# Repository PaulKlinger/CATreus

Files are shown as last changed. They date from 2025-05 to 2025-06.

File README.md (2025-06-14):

# CATreus

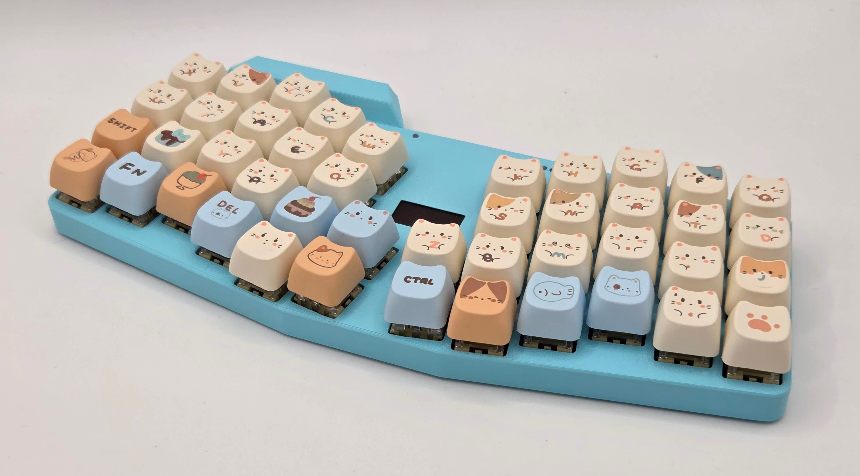
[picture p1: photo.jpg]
photo of keyboard


A wireless keyboard based on the Keyboardio Atreus.

* NRF54L15 Bluetooth SoC (HolyIOT module)
* NPM1300 PMIC for battery management
* 14500 li-ion battery (900mAh)
* 128x64 OLED display (SSD13060based)
* 4 status LEDs, 1 charge LED
* 3D printed [case](/case)
* custom [firmware](/kbd_firmware)
* Kailh Midnight Pro Silent Switches
* MAO profile keycaps ([from Aliexpress](https://www.aliexpress.com/item/1005008664883621.html))
* cat animations by John William Bond (u/Kaimatten), [original video](https://www.reddit.com/r/PixelArt/comments/hoxd95/1_minute_of_1_bit_cat_animations)

Key layout is hardcoded in the firware, I'm using a NEO2 based layout.

## Notes

Programmed via the 5 holes on the top next to the leds, using a custom pogo pin connector.
Spacing is 2.54mm, so can just solder pogo pins to a piece of protoboard.
pinout:
```
   NC    RESET   GND
   3V3   SWDIO   SWCLK
```

Wake button is top left of the center 4 buttons, used to wake the keyboard from sleep mode (30min of inactivity).
UI help by pressing wake + H.

CMD & CTRL keys can be swapped with wake + W for use on Windows/Mac this is persisted per bluetooth connection.

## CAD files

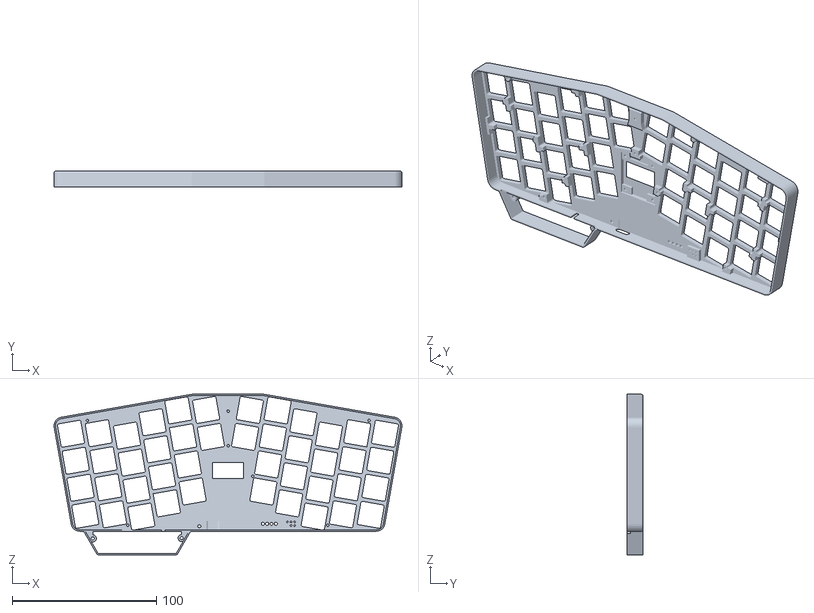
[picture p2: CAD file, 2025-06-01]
case/case_top.stl
240.9 x 10.9 x 111.1

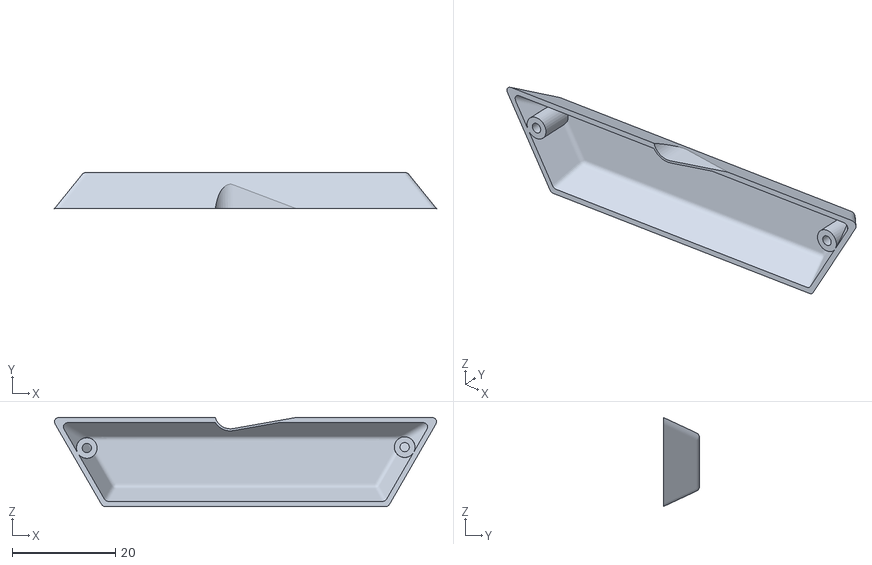
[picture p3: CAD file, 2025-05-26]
case/battery cover.stl
74.0 x 7.00 x 17.3

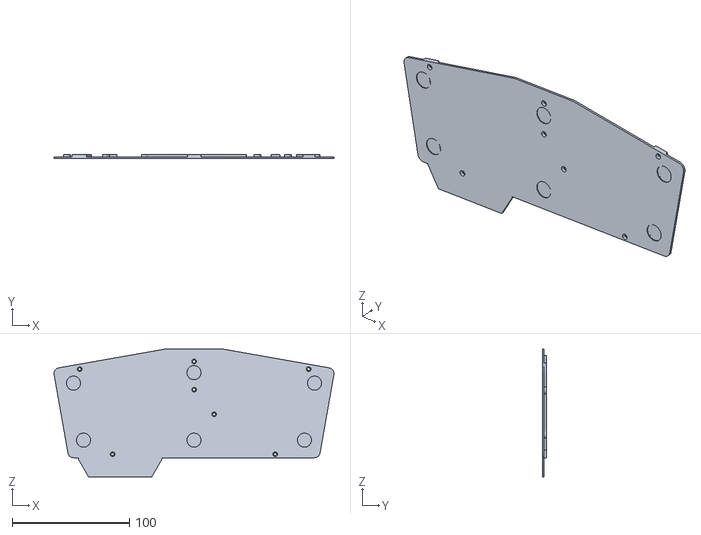
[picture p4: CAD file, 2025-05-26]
case/case_bottom.stl
238.5 x 3.50 x 108.7

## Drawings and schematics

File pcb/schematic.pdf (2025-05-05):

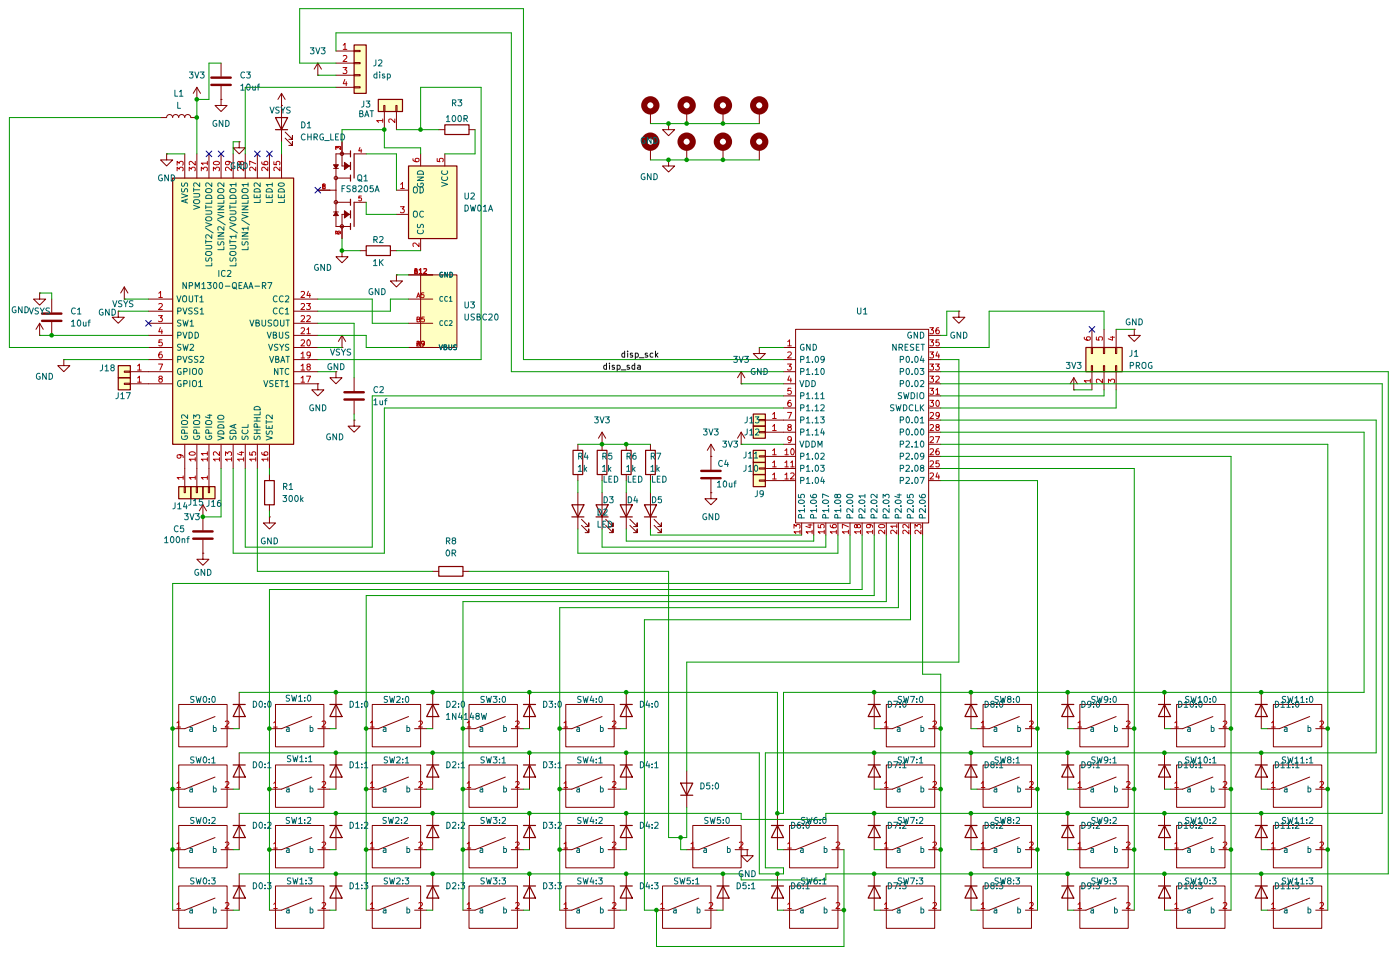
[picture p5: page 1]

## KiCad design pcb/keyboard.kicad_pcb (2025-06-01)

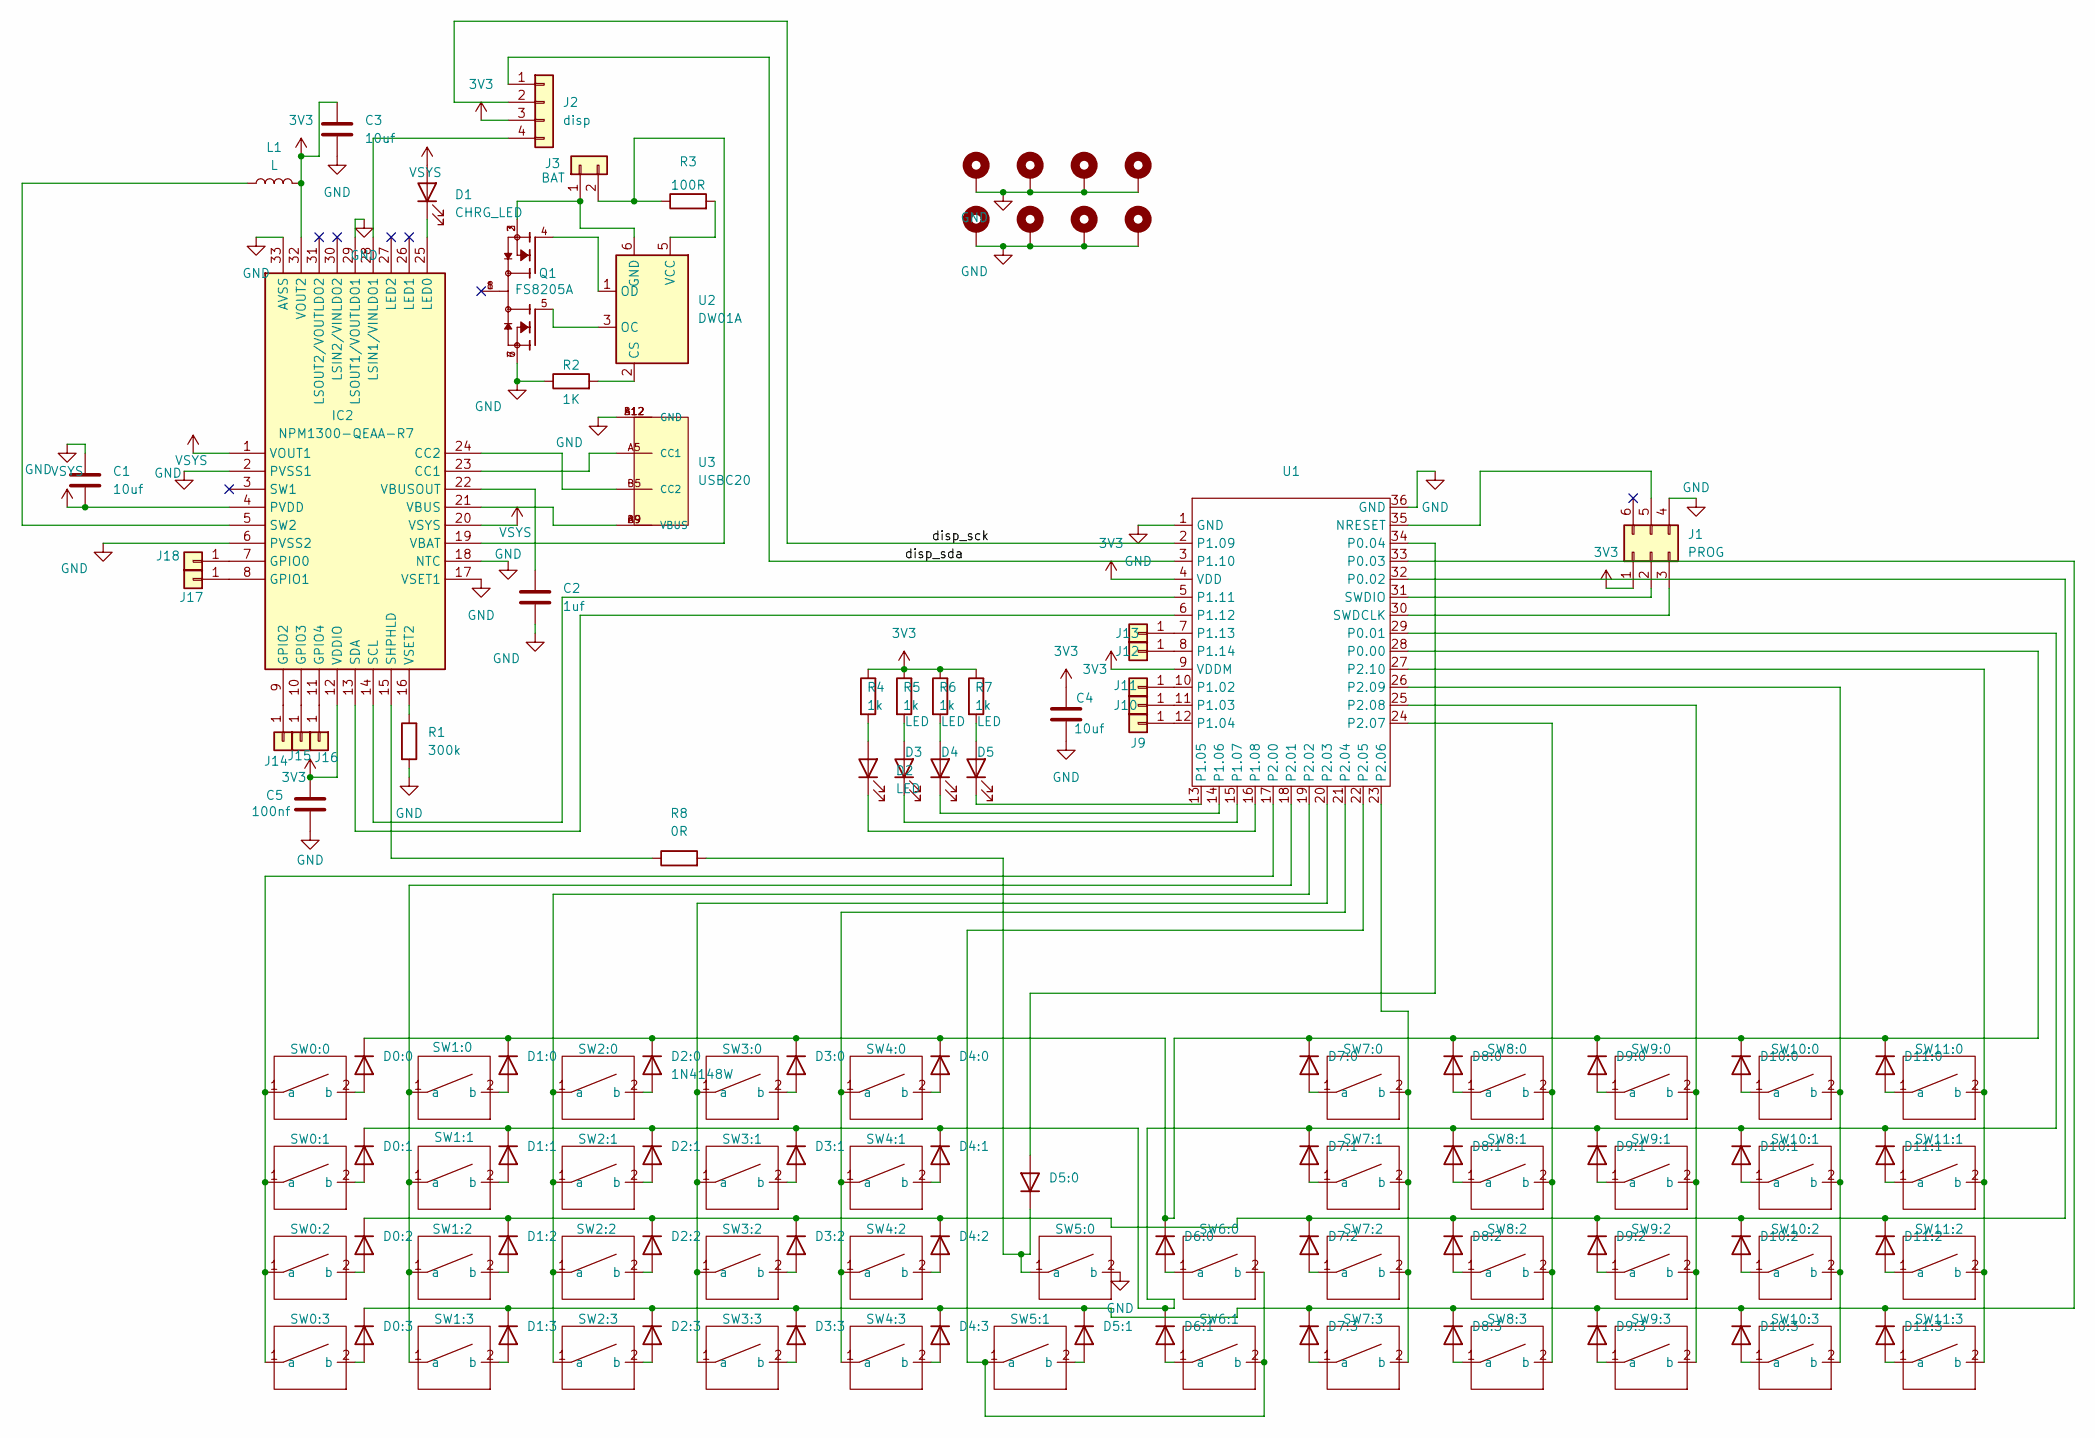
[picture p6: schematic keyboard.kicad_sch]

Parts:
C1, C3, C4: 10uf; C_0805_2012Metric_Pad1.18x1.45mm_HandSolder
C2: 1uf; C_0805_2012Metric_Pad1.18x1.45mm_HandSolder
C5: 100nf; C_0805_2012Metric_Pad1.18x1.45mm_HandSolder
D0:0, D0:1, D0:2, D0:3, D1:0, D1:1, D1:2, D1:3, D2:1, D2:2, D2:3, D3:0, D3:1, D3:2, D3:3, D4:0, D4:1, D4:2, D4:3, D5:0, D5:1, D6:0, D6:1, D7:0, D7:1, D7:2, D7:3, D8:0, D8:1, D8:2, D8:3, D9:0, D9:1, D9:2, D9:3, D10:0, D10:1, D10:2, D10:3, D11:0, D11:1, D11:2, D11:3: Nexperia_CFP3_SOD-123W
D1: CHRG_LED; LED_0805_2012Metric_Pad1.15x1.40mm_HandSolder
D2, D3, D4, D5: LED; LED_0805_2012Metric_Pad1.15x1.40mm_HandSolder
D2:0: 1N4148W; D_SOD-123
H1, H2, H3, H4, H5, H6, H7, H8: MountingHole_Pad; MountingHole_2.2mm_M2_DIN965_Pad
IC2: NPM1300-QEAA-R7; QFN50P500X500X90-33N; Mouser Part Number 949-NPM1300-QEAA-R7
J1: PROG; SWD_PROG_5pin
J2: disp; PinHeader_1x04_P2.54mm_Vertical
J3: BAT; PinHeader_1x02_P2.54mm_Vertical
J9, J10, J11, J12, J13, J14, J15, J16, J17, J18: Conn_01x01; SolderWirePad_1x01_SMD_1x2mm
L1: L; L_1008_2520Metric_Pad1.43x2.20mm_HandSolder
Q1: FS8205A; SOP65P640X120-8N; PARTREV 1.7
R1: 300k; R_0805_2012Metric_Pad1.20x1.40mm_HandSolder
R2: 1K; R_0805_2012Metric_Pad1.20x1.40mm_HandSolder
R3: 100R; R_0805_2012Metric_Pad1.20x1.40mm_HandSolder
R4, R5, R6, R7: 1k; R_0805_2012Metric_Pad1.20x1.40mm_HandSolder
R8: 0R; R_0805_2012Metric_Pad1.20x1.40mm_HandSolder
SW0:0, SW0:1, SW0:2, SW0:3, SW1:0, SW1:1, SW1:2, SW1:3, SW2:0, SW2:1, SW2:2, SW2:3, SW3:0, SW3:1, SW3:2, SW3:3, SW4:0, SW4:1, SW4:2, SW4:3, SW5:0, SW5:1, SW6:0, SW6:1, SW7:0, SW7:1, SW7:2, SW7:3, SW8:0, SW8:1, SW8:2, SW8:3, SW9:0, SW9:1, SW9:2, SW9:3, SW10:0, SW10:1, SW10:2, SW10:3, SW11:0, SW11:1, SW11:2, SW11:3: SW_Cherry_MX_PCB
U1: nrf54l15_holyiot
U2: DW01A; SOT-23-6
U3: USBC20; USBC_6PIN

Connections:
3V3: C3.1, C4.1, C5.1, IC2.12 (VDDIO), IC2.32 (VOUT2), J1.1, J2.3, L1.2, R4.1, R5.1, R6.1, R7.1, U1.4 (VDD), U1.9 (VDDM)
/disp_sck: J2.2, U1.2 (P1.09)
/disp_sda: J2.1, U1.3 (P1.10)
GND: C1.1, C2.2, C3.2, C4.2, C5.2, H1.1, H2.1, H3.1, H4.1, H5.1, H6.1, H7.1, H8.1, IC2.2 (PVSS1), IC2.6 (PVSS2), IC2.17 (VSET1), IC2.18 (NTC), IC2.29 (LSOUT1/VOUTLDO1), IC2.33 (AVSS), J1.4, Q1.6, Q1.7, R1.2, R2.1, SW5:0.2 (b), U1.1 (GND), U1.36 (GND), U3.A12 (GND), U3.B12 (GND)
unnamed: D0:0.2 (A), SW0:0.2 (b)
unnamed: D0:0.1 (K), D1:0.1 (K), D2:0.1 (K), D3:0.1 (K), D4:0.1 (K), D6:0.1 (K), D7:0.1 (K), D8:0.1 (K), D9:0.1 (K), D10:0.1 (K), D11:0.1 (K), U1.28 (P0.00)
unnamed: D0:1.2 (A), SW0:1.2 (b)
unnamed: D0:1.1 (K), D1:1.1 (K), D2:1.1 (K), D3:1.1 (K), D4:1.1 (K), D6:1.1 (K), D7:1.1 (K), D8:1.1 (K), D9:1.1 (K), D10:1.1 (K), D11:1.1 (K), U1.29 (P0.01)
unnamed: D0:2.2 (A), SW0:2.2 (b)
unnamed: D0:2.1 (K), D1:2.1 (K), D2:2.1 (K), D3:2.1 (K), D4:2.1 (K), D7:2.1 (K), D8:2.1 (K), D9:2.1 (K), D10:2.1 (K), D11:2.1 (K), U1.32 (P0.02)
unnamed: D0:3.2 (A), SW0:3.2 (b)
unnamed: D0:3.1 (K), D1:3.1 (K), D2:3.1 (K), D3:3.1 (K), D4:3.1 (K), D5:1.1 (K), D7:3.1 (K), D8:3.1 (K), D9:3.1 (K), D10:3.1 (K), D11:3.1 (K), U1.33 (P0.03)
unnamed: D1.1 (K), IC2.25 (LED0)
unnamed: D1:0.2 (A), SW1:0.2 (b)
unnamed: D1:1.2 (A), SW1:1.2 (b)
unnamed: D1:2.2 (A), SW1:2.2 (b)
unnamed: D1:3.2 (A), SW1:3.2 (b)
unnamed: D2.2 (A), R4.2
unnamed: D2.1 (K), U1.16 (P1.08)
unnamed: D2:0.2 (A), SW2:0.2 (b)
unnamed: D2:1.2 (A), SW2:1.2 (b)
unnamed: D2:2.2 (A), SW2:2.2 (b)
unnamed: D2:3.2 (A), SW2:3.2 (b)
unnamed: D3.2 (A), R5.2
unnamed: D3.1 (K), U1.15 (P1.07)
unnamed: D3:0.2 (A), SW3:0.2 (b)
unnamed: D3:1.2 (A), SW3:1.2 (b)
unnamed: D3:2.2 (A), SW3:2.2 (b)
unnamed: D3:3.2 (A), SW3:3.2 (b)
unnamed: D4.2 (A), R6.2
unnamed: D4.1 (K), U1.14 (P1.06)
unnamed: D4:0.2 (A), SW4:0.2 (b)
unnamed: D4:1.2 (A), SW4:1.2 (b)
unnamed: D4:2.2 (A), SW4:2.2 (b)
unnamed: D4:3.2 (A), SW4:3.2 (b)
unnamed: D5.2 (A), R7.2
unnamed: D5.1 (K), U1.13 (P1.05)
unnamed: D5:0.2 (A), U1.34 (P0.04)
unnamed: D5:0.1 (K), R8.2, SW5:0.1 (a)
unnamed: D5:1.2 (A), SW5:1.2 (b)
unnamed: D6:0.2 (A), SW6:0.1 (a)
unnamed: D6:1.2 (A), SW6:1.1 (a)
unnamed: D7:0.2 (A), SW7:0.1 (a)
unnamed: D7:1.2 (A), SW7:1.1 (a)
unnamed: D7:2.2 (A), SW7:2.1 (a)
unnamed: D7:3.2 (A), SW7:3.1 (a)
unnamed: D8:0.2 (A), SW8:0.1 (a)
unnamed: D8:1.2 (A), SW8:1.1 (a)
unnamed: D8:2.2 (A), SW8:2.1 (a)
unnamed: D8:3.2 (A), SW8:3.1 (a)
unnamed: D9:0.2 (A), SW9:0.1 (a)
unnamed: D9:1.2 (A), SW9:1.1 (a)
unnamed: D9:2.2 (A), SW9:2.1 (a)
unnamed: D9:3.2 (A), SW9:3.1 (a)
unnamed: D10:0.2 (A), SW10:0.1 (a)
unnamed: D10:1.2 (A), SW10:1.1 (a)
unnamed: D10:2.2 (A), SW10:2.1 (a)
unnamed: D10:3.2 (A), SW10:3.1 (a)
unnamed: D11:0.2 (A), SW11:0.1 (a)
unnamed: D11:1.2 (A), SW11:1.1 (a)
unnamed: D11:2.2 (A), SW11:2.1 (a)
unnamed: D11:3.2 (A), SW11:3.1 (a)
unnamed: IC2.23 (CC1), U3.A5 (CC1)
unnamed: IC2.24 (CC2), U3.B5 (CC2)
unnamed: IC2.7 (GPIO0), J18.1
unnamed: IC2.8 (GPIO1), J17.1
unnamed: IC2.9 (GPIO2), J14.1
unnamed: IC2.10 (GPIO3), J15.1
unnamed: IC2.11 (GPIO4), J16.1
unnamed: IC2.28 (LSIN1/VINLDO1), J2.4
unnamed: IC2.14 (SCL), U1.5 (P1.11)
unnamed: IC2.13 (SDA), U1.6 (P1.12)
unnamed: IC2.15 (SHPHLD), R8.1
unnamed: IC2.5 (SW2), L1.1
unnamed: IC2.19 (VBAT), J3.2, R3.1
unnamed: IC2.21 (VBUS), U3.A9 (VBUS), U3.B9 (VBUS)
unnamed: C2.1, IC2.22 (VBUSOUT)
unnamed: IC2.16 (VSET2), R1.1
unnamed: J1.2, U1.31 (SWDIO)
unnamed: J1.3, U1.30 (SWDCLK)
unnamed: J1.5, U1.35 (NRESET)
unnamed: J3.1, Q1.2, Q1.3, U2.6 (GND)
unnamed: J9.1, U1.12 (P1.04)
unnamed: J10.1, U1.11 (P1.03)
unnamed: J11.1, U1.10 (P1.02)
unnamed: J12.1, U1.8 (P1.14)
unnamed: J13.1, U1.7 (P1.13)
unnamed: SW0:0.1 (a), SW0:1.1 (a), SW0:2.1 (a), SW0:3.1 (a), U1.17 (P2.00)
unnamed: SW1:0.1 (a), SW1:1.1 (a), SW1:2.1 (a), SW1:3.1 (a), U1.18 (P2.01)
unnamed: SW2:0.1 (a), SW2:1.1 (a), SW2:2.1 (a), SW2:3.1 (a), U1.19 (P2.02)
unnamed: SW3:0.1 (a), SW3:1.1 (a), SW3:2.1 (a), SW3:3.1 (a), U1.20 (P2.03)
unnamed: SW4:0.1 (a), SW4:1.1 (a), SW4:2.1 (a), SW4:3.1 (a), U1.21 (P2.04)
unnamed: SW5:1.1 (a), SW6:0.2 (b), SW6:1.2 (b), U1.22 (P2.05)
unnamed: SW7:0.2 (b), SW7:1.2 (b), SW7:2.2 (b), SW7:3.2 (b), U1.23 (P2.06)
unnamed: SW8:0.2 (b), SW8:1.2 (b), SW8:2.2 (b), SW8:3.2 (b), U1.24 (P2.07)
unnamed: SW9:0.2 (b), SW9:1.2 (b), SW9:2.2 (b), SW9:3.2 (b), U1.25 (P2.08)
unnamed: SW10:0.2 (b), SW10:1.2 (b), SW10:2.2 (b), SW10:3.2 (b), U1.26 (P2.09)
unnamed: SW11:0.2 (b), SW11:1.2 (b), SW11:2.2 (b), SW11:3.2 (b), U1.27 (P2.10)
unnamed: R2.2, U2.2 (CS)
unnamed: Q1.5, U2.3 (OC)
unnamed: Q1.4, U2.1 (OD)
unnamed: R3.2, U2.5 (VCC)
VSYS: C1.2, D1.2 (A), IC2.1 (VOUT1), IC2.4 (PVDD), IC2.20 (VSYS)

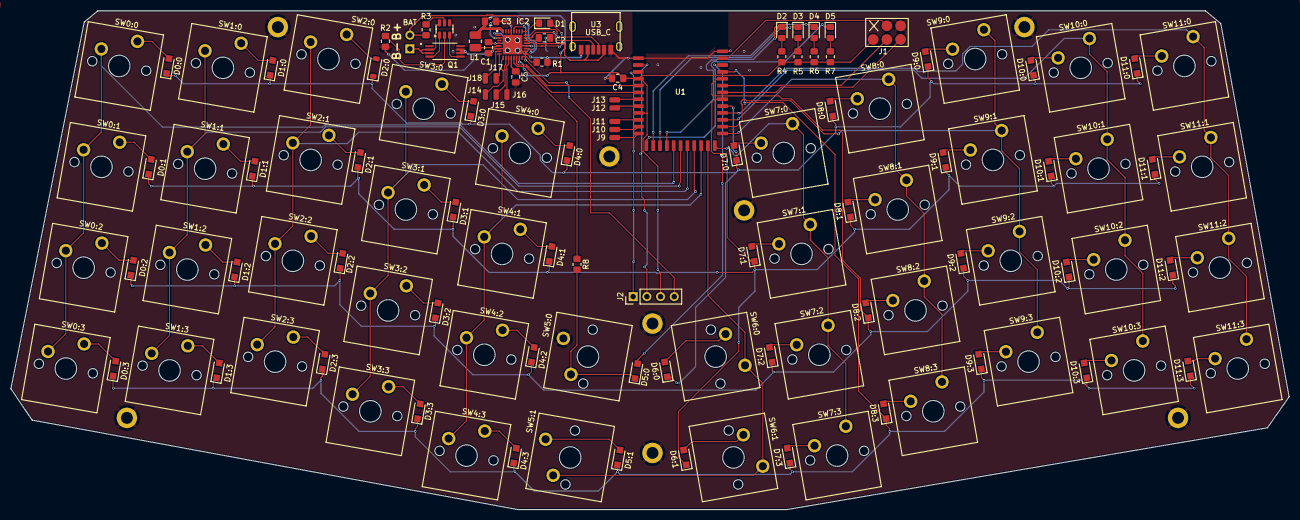
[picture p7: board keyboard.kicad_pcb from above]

Board: 2 copper layers, 237.1 x 92.5 mm, 133 parts (1 on the bottom side), 103 nets.

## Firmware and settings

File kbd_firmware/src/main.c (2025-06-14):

#include <errno.h>
#include <stddef.h>
#include <stdio.h>
#include <string.h>
#include <zephyr/bluetooth/bluetooth.h>
#include <zephyr/bluetooth/conn.h>
#include <zephyr/bluetooth/gatt.h>
#include <zephyr/bluetooth/hci.h>
#include <zephyr/bluetooth/uuid.h>
#include <zephyr/drivers/gpio.h>
#include <zephyr/drivers/i2c.h>
#include <zephyr/drivers/regulator.h>
#include <zephyr/drivers/sensor/npm1300_charger.h>
#include <zephyr/drivers/uart.h>
#include <zephyr/kernel.h>
#include <zephyr/settings/settings.h>
#include <zephyr/sys/byteorder.h>
#include <zephyr/sys/printk.h>
#include <zephyr/types.h>

#include "bluetooth.h"
#include "config.h"
#include "fuel_gauge/fuel_gauge.h"
#include "key_layout.h"
#include "key_matrix.h"
#include "leds.h"
#include "nvs.h"
#include "pmic.h"
#include "ui.h"

void i2c_scanner(const struct device *bus) {
  uint8_t error = 0u;
  uint8_t dst;
  uint8_t i2c_dev_cnt = 0;
  struct i2c_msg msgs[1];
  msgs[0].buf = &dst;
  msgs[0].len = 1U;
  msgs[0].flags = I2C_MSG_WRITE | I2C_MSG_STOP;

  /* Use the full range of I2C address for display purpose */
  for (uint16_t x = 0; x <= 0x7f; x++) {
    /* New line every 0x10 address */
    if (x % 0x10 == 0) {
      printk("|\n0x%02x| ", x);
    }
    /* Range the test with the start and stop value configured in the
     * kconfig */
    if (x >= 0 && x <= 0x7f) {
      /* Send the address to read from */
      error = i2c_transfer(bus, &msgs[0], 1, x);
      /* I2C device found on current address */
      if (error == 0) {
        printk("0x%02x ", x);
        i2c_dev_cnt++;
      } else {
        printk(" --  ");
      }
    } else {
      /* Scan value out of range, not scanned */
      printk("     ");
    }
  }
  printk("|\n");
  printk("\nI2C device(s) found on the bus: %d\nScanning done.\n\n",
         i2c_dev_cnt);
  printk(
      "Find the registered I2C address on: "
      "https://i2cdevices.org/addresses\n\n");
}

int main(void) {
  int ret;
  printk("Starting wrls atreus\n");
  k_msleep(50);
  init_leds();

  init_ui();
  ui_send_startup();

  nvs_init();

  int err;
  err = init_bluetooth();
  if (err) {
    printk("Bluetooth init failed (err %d)\n", err);
    return 0;
  }
  init_pmic();

  init_fuel_gauge();

  printk("Init key matrix\n");
  init_key_matrix();
  uint32_t last_active_time = k_uptime_seconds();
  uint32_t last_no_pressed_time = last_active_time;

  uint32_t last_bas_sent = k_uptime_seconds();
  send_bas_soc(battery_state.soc);

  while (1) {
    uint32_t seconds_since_active = k_uptime_seconds() - last_active_time;
    uint32_t seconds_since_no_pressed =
        k_uptime_seconds() - last_no_pressed_time;
    if ((seconds_since_active > DEEP_SLEEP_TIMEOUT_S) ||
        ((seconds_since_active > DEEP_SLEEP_ADVERTISING_TIMEOUT_S) &&
         ble_is_advertising()) ||
        (seconds_since_no_pressed > DEEP_SLEEP_NO_PRESSED_TIMEOUT_S)) {
      printk("No activity for %ds, going to deep sleep\n",
             seconds_since_active);
      ui_send_wake_and_key((struct key_coord){1, 6});  // S
    }

    read_key_matrix();

    if (!eq_pressed_keys(last_pressed_keys, current_pressed_keys)) {
      last_active_time = k_uptime_seconds();

      if (current_pressed_keys.wake_pressed) {
        if (current_pressed_keys.n_pressed > 0) {
          ui_send_wake_and_key(current_pressed_keys.keys[0]);
        } else if (!last_pressed_keys.wake_pressed) {
          ui_send_wake();
        }
      } else {
        // applications take exclusive control of the keys
        // so only send them to the host if they are not running
        if (application_running) {
          // send empty to clear any previous keys
          send_encoded_keys((struct encoded_keys){0});  // send empty keys
        } else {
          struct encoded_keys encoded_keys = get_encoded_keys();
          send_encoded_keys(encoded_keys);
        }
      }
      if (ui_active() && current_pressed_keys.n_pressed > 0) {
        // TODO: doesn't really make sense, maybe just get rid of the key
        // message?
        ui_send_key(current_pressed_keys.keys[0]);
      }
    }

    if (current_pressed_keys.n_pressed == 0 &&
        !current_pressed_keys.wake_pressed) {
      last_no_pressed_time = k_uptime_seconds();
    }

    if (k_uptime_seconds() - last_bas_sent > BAS_SOC_INTERVAL_S) {
      last_bas_sent = k_uptime_seconds();
      send_bas_soc(battery_state.soc);
      printk("Sent battery SOC %d", (uint8_t)battery_state.soc);
    }

    if (current_pressed_keys.n_pressed > 0 ||
        current_pressed_keys.wake_pressed) {
      // if keys are pressed always sleep for 50ms
      // (we can't use the level interrupt here)
      // TODO: could switch to edge interrupt in this case??
      k_msleep(50);
    } else {
      ret = wait_for_key(2000);
    }
  }

  return 0;
}

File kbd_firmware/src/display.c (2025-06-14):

#include "display.h"

#include <errno.h>
#include <math.h>
#include <stddef.h>
#include <stdlib.h>
#include <string.h>
#include <zephyr/drivers/gpio.h>
#include <zephyr/drivers/i2c.h>
#include <zephyr/drivers/regulator.h>
#include <zephyr/kernel.h>
#include <zephyr/sys/byteorder.h>
#include <zephyr/sys/printk.h>
#include <zephyr/types.h>

const char FONT[][6] = {
    {0x00, 0x00, 0x00, 0x00, 0x00, 0x00},  // sp
    {0x00, 0x00, 0x00, 0x2f, 0x00, 0x00},  // !
    {0x00, 0x00, 0x07, 0x00, 0x07, 0x00},  // "
    {0x00, 0x14, 0x7f, 0x14, 0x7f, 0x14},  // #
    {0x00, 0x24, 0x2a, 0x7f, 0x2a, 0x12},  // $
    {0x00, 0x62, 0x64, 0x08, 0x13, 0x23},  // %
    {0x00, 0x36, 0x49, 0x55, 0x22, 0x50},  // &
    {0x00, 0x00, 0x05, 0x03, 0x00, 0x00},  // '
    {0x00, 0x00, 0x1c, 0x22, 0x41, 0x00},  // (
    {0x00, 0x00, 0x41, 0x22, 0x1c, 0x00},  // )
    {0x00, 0x14, 0x08, 0x3E, 0x08, 0x14},  // *
    {0x00, 0x08, 0x08, 0x3E, 0x08, 0x08},  // +
    {0x00, 0x00, 0x00, 0xA0, 0x60, 0x00},  // ,
    {0x00, 0x08, 0x08, 0x08, 0x08, 0x08},  // -
    {0x00, 0x00, 0x60, 0x60, 0x00, 0x00},  // .
    {0x00, 0x20, 0x10, 0x08, 0x04, 0x02},  // /
    {0x00, 0x3E, 0x51, 0x49, 0x45, 0x3E},  // 0
    {0x00, 0x00, 0x42, 0x7F, 0x40, 0x00},  // 1
    {0x00, 0x42, 0x61, 0x51, 0x49, 0x46},  // 2
    {0x00, 0x21, 0x41, 0x45, 0x4B, 0x31},  // 3
    {0x00, 0x18, 0x14, 0x12, 0x7F, 0x10},  // 4
    {0x00, 0x27, 0x45, 0x45, 0x45, 0x39},  // 5
    {0x00, 0x3C, 0x4A, 0x49, 0x49, 0x30},  // 6
    {0x00, 0x01, 0x71, 0x09, 0x05, 0x03},  // 7
    {0x00, 0x36, 0x49, 0x49, 0x49, 0x36},  // 8
    {0x00, 0x06, 0x49, 0x49, 0x29, 0x1E},  // 9
    {0x00, 0x00, 0x36, 0x36, 0x00, 0x00},  // :
    {0x00, 0x00, 0x56, 0x36, 0x00, 0x00},  // ;
    {0x00, 0x08, 0x14, 0x22, 0x41, 0x00},  // <
    {0x00, 0x14, 0x14, 0x14, 0x14, 0x14},  // =
    {0x00, 0x00, 0x41, 0x22, 0x14, 0x08},  // >
    {0x00, 0x02, 0x01, 0x51, 0x09, 0x06},  // ?
    {0x00, 0x32, 0x49, 0x59, 0x51, 0x3E},  // @
    {0x00, 0x7C, 0x12, 0x11, 0x12, 0x7C},  // A
    {0x00, 0x7F, 0x49, 0x49, 0x49, 0x36},  // B
    {0x00, 0x3E, 0x41, 0x41, 0x41, 0x22},  // C
    {0x00, 0x7F, 0x41, 0x41, 0x22, 0x1C},  // D
    {0x00, 0x7F, 0x49, 0x49, 0x49, 0x41},  // E
    {0x00, 0x7F, 0x09, 0x09, 0x09, 0x01},  // F
    {0x00, 0x3E, 0x41, 0x49, 0x49, 0x7A},  // G
    {0x00, 0x7F, 0x08, 0x08, 0x08, 0x7F},  // H
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
    {0x00, 0x55, 0x2A, 0x55, 0x2A, 0x55},  // backslash
    {0x00, 0x00, 0x41, 0x41, 0x7F, 0x00},  // ]
    {0x00, 0x04, 0x02, 0x01, 0x02, 0x04},  // ^
    {0x00, 0x40, 0x40, 0x40, 0x40, 0x40},  // _
    {0x00, 0x00, 0x01, 0x02, 0x04, 0x00},  // '
    {0x00, 0x20, 0x54, 0x54, 0x54, 0x78},  // a
    {0x00, 0x7F, 0x48, 0x44, 0x44, 0x38},  // b
    {0x00, 0x38, 0x44, 0x44, 0x44, 0x20},  // c
    {0x00, 0x38, 0x44, 0x44, 0x48, 0x7F},  // d
    {0x00, 0x38, 0x54, 0x54, 0x54, 0x18},  // e
    {0x00, 0x08, 0x7E, 0x09, 0x01, 0x02},  // f
    {0x00, 0x18, 0xA4, 0xA4, 0xA4, 0x7C},  // g
    {0x00, 0x7F, 0x08, 0x04, 0x04, 0x78},  // h
    {0x00, 0x00, 0x44, 0x7D, 0x40, 0x00},  // i
    {0x00, 0x40, 0x80, 0x84, 0x7D, 0x00},  // j
    {0x00, 0x7F, 0x10, 0x28, 0x44, 0x00},  // k
    {0x00, 0x00, 0x41, 0x7F, 0x40, 0x00},  // l
    {0x00, 0x7C, 0x04, 0x18, 0x04, 0x78},  // m
    {0x00, 0x7C, 0x08, 0x04, 0x04, 0x78},  // n
    {0x00, 0x38, 0x44, 0x44, 0x44, 0x38},  // o
    {0x00, 0xFC, 0x24, 0x24, 0x24, 0x18},  // p
    {0x00, 0x18, 0x24, 0x24, 0x18, 0xFC},  // q
    {0x00, 0x7C, 0x08, 0x04, 0x04, 0x08},  // r
    {0x00, 0x48, 0x54, 0x54, 0x54, 0x20},  // s
    {0x00, 0x04, 0x3F, 0x44, 0x40, 0x20},  // t
    {0x00, 0x3C, 0x40, 0x40, 0x20, 0x7C},  // u
    {0x00, 0x1C, 0x20, 0x40, 0x20, 0x1C},  // v
    {0x00, 0x3C, 0x40, 0x30, 0x40, 0x3C},  // w
    {0x00, 0x44, 0x28, 0x10, 0x28, 0x44},  // x
    {0x00, 0x1C, 0xA0, 0xA0, 0xA0, 0x7C},  // y
    {0x00, 0x44, 0x64, 0x54, 0x4C, 0x44},  // z
    {0x00, 0x00, 0x08, 0x77, 0x41, 0x00},  // {
    {0x00, 0x00, 0x00, 0x63, 0x00, 0x00},  // ¦
    {0x00, 0x00, 0x41, 0x77, 0x08, 0x00},  // }
    {0x00, 0x08, 0x04, 0x08, 0x08, 0x04},  // ~
};

#define LCD_DISP_OFF 0xAE
#define LCD_DISP_ON 0xAF

const uint8_t init_sequence[] = {
    // Initialization Sequence
    LCD_DISP_OFF,  // Display OFF (sleep mode)
    0x20,
    0b00,  // Set Memory Addressing Mode
    // 00=Horizontal Addressing Mode; 01=Vertical Addressing Mode;
    // 10=Page Addressing Mode (RESET); 11=Invalid
    0xB0,  // Set Page Start Address for Page Addressing Mode, 0-7
    0xC0,  // Set COM Output Scan Direction
    0x00,  // --set low column address
    0x10,  // --set high column address
    0x40,  // --set start line address
    0x81,
    0xFF,  // Set contrast control register
    0xA0,  // Set Segment Re-map. A0=address mapped; A1=address 127 mapped.
    0xA6,  // Set display mode. A6=Normal; A7=Inverse
    0xA8,
    0x3F,  // Set multiplex ratio(1 to 64)
    0xA4,  // Output RAM to Display
    // 0xA4=Output follows RAM content; 0xA5,Output ignores RAM content
    0xD3,
    0x00,        // Set display offset. 00 = no offset
    0xD5,        // --set display clock divide ratio/oscillator frequency
    0b11110000,  // --set divide ratio
    0xD9,
    0x22,  // Set pre-charge period
    0xDA,
    0x12,  // Set com pins hardware configuration
    0xDB,  // --set vcomh
    0x20,  // 0x20,0.77xVcc
    0x8D,
    0x14,  // Set DC-DC enable
    LCD_DISP_ON,
};

#define I2C21_NODE DT_NODELABEL(display)
static const struct i2c_dt_spec dev_i2c = I2C_DT_SPEC_GET(I2C21_NODE);
static const struct device *disp_ldsw =
    DEVICE_DT_GET(DT_NODELABEL(npm1300_ek_ldo1));

static struct {
  uint8_t x;
  uint8_t y;
} cursorPosition;

uint8_t displayBuffer[DISPLAY_HEIGHT / 8][DISPLAY_WIDTH];

void init_i2c(void) {
  while (!device_is_ready(dev_i2c.bus)) {
    printk("I2C bus %s is not ready\n", dev_i2c.bus->name);
    k_sleep(K_MSEC(100));
  };
}

int lcd_command(const uint8_t *cmds, size_t len) {
  struct i2c_msg mode_msg;
  uint8_t is_command = 0x00;
  mode_msg.buf = &is_command;
  mode_msg.len = 1;
  mode_msg.flags = I2C_MSG_WRITE;

  struct i2c_msg data_msg;
  data_msg.buf = (uint8_t *)cmds;
  data_msg.len = len;
  data_msg.flags = I2C_MSG_WRITE | I2C_MSG_STOP;

  struct i2c_msg msgs[] = {mode_msg, data_msg};
  int ret = i2c_transfer(dev_i2c.bus, msgs, 2, dev_i2c.addr);
  if (ret != 0) {
    printk("Error %d: failed to write command to the display\n", ret);
  }
  return ret;
}

int lcd_data(const uint8_t *data, size_t len) {
  struct i2c_msg mode_msg;
  uint8_t is_data = 0x40;
  mode_msg.buf = &is_data;
  mode_msg.len = 1;
  mode_msg.flags = I2C_MSG_WRITE;

  struct i2c_msg data_msg;
  data_msg.buf = (uint8_t *)data;
  data_msg.len = len;
  data_msg.flags = I2C_MSG_WRITE | I2C_MSG_STOP;

  struct i2c_msg msgs[] = {mode_msg, data_msg};
  int ret = i2c_transfer(dev_i2c.bus, msgs, 2, dev_i2c.addr);
  if (ret != 0) {
    printk("Error %d: failed to write data to the display\n", ret);
  }
  return ret;
}

void lcd_goto_xpix_y(uint8_t x, uint8_t y) {
  cursorPosition.x = x;
  cursorPosition.y = y;
}
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

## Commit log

2025-05-03 wip kicad pcb
    [keyboard.kicad_pcb, keyboard.kicad_sch]
2025-05-04 ~finished schematic, started layout
    [keyboard.kicad_pcb, keyboard.kicad_sch]
2025-05-05 v1.0 PCB (jlcpcb order)
    [keyboard-B_Cu.gbl, keyboard-B_Mask.gbs, keyboard-B_Paste.gbp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]
2025-05-05 pdf schematic
    [keyboard.kicad_sch]
2025-05-18 custom board, working battery charger & uart logging
2025-05-21 keyboard matrix reading, wake on interrupt
2025-05-24 ship mode on wake + s, dcdc mode for vregmain, increased uart baud
2025-05-25 v1 case
    [battery cover.stl, case_bottom.stl, case_top.stl]
2025-05-26 basic ui framework, wip
2025-05-26 finished (?) case
    [case_bottom.stl, case_top.stl]
2025-05-26 led control, advertising animation, various tweaks
2025-05-26 handle repairing, tweaks. Currently works on android/windows but not mac :(
2025-05-26 bugfix in layout, only change layers from layer 0 (not sure I'll keep that)
    [main.c]
2025-05-26 add sleep to ensure ui thread has suspended
2025-05-26 case for first fully assembled version
    [battery cover.stl, case_top.stl]
2025-05-27 keep track of current/last key state in key_matrix, new help page, option to swap ctrl & cmd
    [key_matrix.c, main.c]
2025-05-27 handle layer switches more gracefully by keeping track of active layer when keys were pressed, correct alt key mapping
    [main.c]
2025-05-28 go to sleep if keys are constantly pressed to avoid battery drain
    [main.c]
2025-05-31 wakeup animation, increase i2c speed
2025-05-31 add notebook to convert animation frames to displaybuffer
2025-05-31 try to make display les flickery (not sure it did anything)
2025-05-31 nvs for n boot count, wip storing cmd/ctrl state (not working yet)
    [main.c]
2025-06-01 disable uart logging
2025-06-01 add pre-commit hooks, run formatter on firmware
    [defaults.cfg]
2025-06-01 tweak display cover
    [case_top.stl]
2025-06-01 move/reorg pcb folder
    [keyboard-B_Cu.gbl, keyboard-B_Mask.gbs, keyboard-B_Paste.gbp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]
2025-06-13 add fuel gauge for battery soc
2025-06-14 send battery state
